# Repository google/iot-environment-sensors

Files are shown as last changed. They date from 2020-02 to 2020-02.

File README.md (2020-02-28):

This project demonstrates how an ESP32 can be combined with Google Cloud IoT, Google Cloud Functions, Google StackDriver and Google BigQuery to collect and analyze metrics from environmental sensors.

**This example is not an officially supported Google product, does not have a SLA/SLO, and should not be used in production.**

The project consists of three components:

- The Google Cloud Function - This is a simple Go-based piece of code. Simply configure the Cloud Function in the console to be triggered on a telemetry event from the IoT project.
- The firmware - This is an ESP-IDF project and must be built using the ESP-IDF toolset.
- A CAD model for the PCB design in [this repository](https://github.com/bobobo1618/iot-environment-sensor).

# Instructions

There are three things that have to be set up:

- The hardware
- The firmware
- The Google Cloud Platform project which will collect metrics for analysis

## Hardware

This has been tested with the PCB design from [this repository](https://github.com/bobobo1618/iot-environment-sensor). The board is intended to be combined with:

- A Sensirion SCD30 CO2 sensor, with a pin-header soldered to it.
- An Amphenol SM-UART-04L particulate sensor.
- An ESP32-PICO-KIT.

The board can be manufactured manually or by a PCB fab.

This repository also contains a FreeCAD model for a case intended to fit the PCB design.

## Google Cloud Platform

The project is intended to be used with:

- IoT Core: To act as a bridge between the MQTT protocol used by the sensors and Pubsub.
- Pubsub: To act as a bridge between IoT Core and Cloud Functions.
- StackDriver: For real-time monitoring and alerting on sensor readings.
- BigQuery: For long-term historical data collection and analysis.
- Cloud Functions: To ingest incoming data and store it in BigQuery and/or StackDriver.

The recommended setup procedure is (using the [Cloud SDK](https://cloud.google.com/sdk) CLI):

- Create a GCP project ([docs](https://cloud.google.com/resource-manager/docs/creating-managing-projects)): `gcloud projects create <PROJECT_ID>`
- Create an IoT Core registry in the region of your choice ([docs](https://cloud.google.com/iot/docs/how-tos/devices)): `gcloud iot registries create <REGISTRY_ID> --project=<PROJECT_ID> --region=<REGION>`
- Create the partitioned BigQuery table where your historical data will be stored ([docs](https://cloud.google.com/bigquery/docs/creating-column-partitions)): `bq mk --table --schema bqschema.json --time_partitioning_field Timestamp <PROJECT_ID>:<DATASET>.<TABLE>`
- Set up the Cloud Functions ([docs](https://cloud.google.com/functions/docs/deploying/filesystem)):
    - BigQuery: 
      ```bash
      gcloud functions deploy <NAME> \
        --runtime go111 \
        --trigger-topic telemetry \
        --entry-point GasTranslator \
        --memory 128MB \
        --source cloud_function \
        --set-env-vars=PROJECT_ID=<PROJECT_ID>,BQ_DATASET=<BQ_DATASET>,BQ_TABLE=<BQ_TABLE>
      ```
    - StackDriver:
    ```bash
      gcloud functions deploy <NAME> \
        --runtime go111 \
        --trigger-topic telemetry \
        --entry-point GasTranslatorStackdriver \
        --memory 128MB \
        --source cloud_function \
        --set-env-vars=PROJECT_ID=<PROJECT_ID>,SD_NAMESPACE=<SD_NAMESPACE>,SD_LOCATION=<SD_LOCATION>,
      ```

## Firmware

The firmware is an [Espressif ESP-IDF](https://docs.espressif.com/projects/esp-idf/en/latest/) project and in particular uses [arduino-esp32](https://github.com/espressif/arduino-esp32). As such, it depends on version 3.3.1 of ESP-IDF which can be installed following [these instructions](https://docs.espressif.com/projects/esp-idf/en/v3.3.1/get-started/index.html). arduino-esp32 frequently updates its IDF version so check the git log for the most recent commit hash:

```bash
cd firmware/components/arduino
git log --oneline --grep 'IDF' firmware/components/arduino/
```

Once you've set up ESP-IDF, you'll need to configure the project by running `idf.py menuconfig` from the firmware directory. In particular, under `Component Config -> Google IoT Configuration` there are options for the IoT Core project and registry, as well as the WiFi AP and password.

The firmware is also built with support for OTA firmware updates and requires that you generate an OTA signing key. To do so:

- Generate a private key: `espsecure.py generate_signing_key secure_boot_signing_key.pem`
- Generate a public key: `espsecure.py extract_public_key --keyfile secure_boot_signing_key.pem signature_verification_key.bin`

The next step is to build the firmware with `idf.py build`.

Finally, you need to flash the device and provision if for IoT Core. The `provision.sh` script does both.

### OTAs

The firmware assumes that the firmware update will be stored using Google Cloud Storage. If you want to store it elsewhere, you'll need to replace `googleca.pem` with the public certificate of the HTTPS server you intend to update from.

In order to send an OTA update, you must:

- Build: `idf.py build`
- Sign: `espsecure.py sign_data --keyfile secure_boot_signing_key.pem build/hello-world.bin`
- Upload to your HTTPS server: `gsutil cp -a public-read build/hello-world.bin gs://<your bucket>/firmware.bin`
- Send the update command using IoT Core:
  ```
  gcloud iot devices commands send \
    --device=<device id> \
    --project=<project> \
    --region=<region> \
    --registry=<registry> \
    --command-data='update: https://storage.googleapis.com/<your bucket>/firmware.bin'
  ```

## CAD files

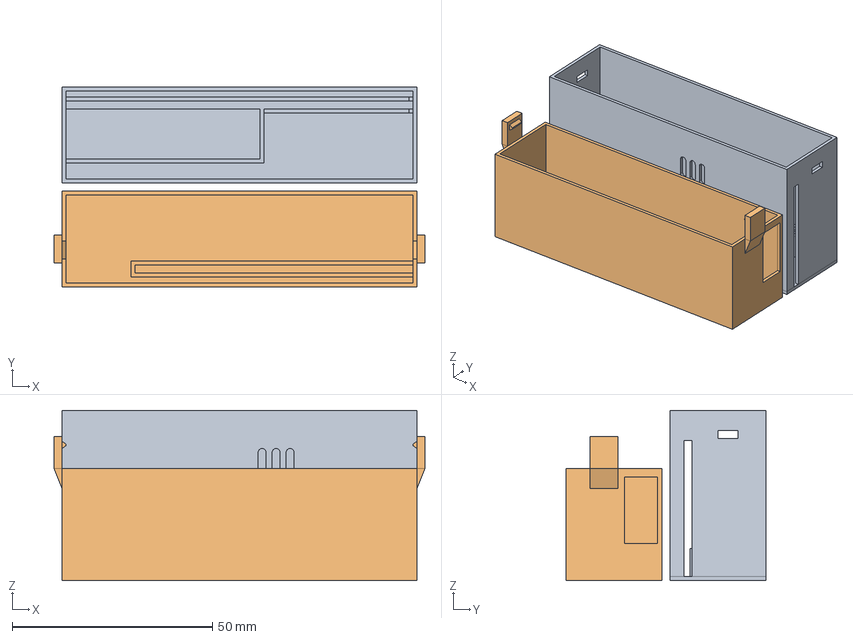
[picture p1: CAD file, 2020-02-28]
case_extended.FCStd
92.7 x 50.0 x 42.5 mm
CaseBody
LidBody

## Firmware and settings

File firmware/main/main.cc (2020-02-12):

// Copyright 2020 Google LLC
//
// Licensed under the Apache License, Version 2.0 (the "License");
// you may not use this file except in compliance with the License.
// You may obtain a copy of the License at
//
//      http://www.apache.org/licenses/LICENSE-2.0
//
// Unless required by applicable law or agreed to in writing, software
// distributed under the License is distributed on an "AS IS" BASIS,
// WITHOUT WARRANTIES OR CONDITIONS OF ANY KIND, either express or implied.
// See the License for the specific language governing permissions and
// limitations under the License.

#include <EEPROM.h>
#include <FS.h>
#include <HTTPClient.h>
#include <SPIFFS.h>
#include <WiFi.h>
#include <WiFiMulti.h>
#include <Wire.h>
#include <esp_system.h>
#include <freertos/FreeRTOS.h>
#include <freertos/task.h>

#include <array>
#include <cinttypes>
#include <string>

#include "google-mqtt.h"
#include "sensor_bmp280.h"
#include "sensor_scd30.h"
#include "sensor_sgp30.h"
#include "sensor_smuart04l.h"

SemaphoreHandle_t i2c_mutex;

#define WIFI_REPORTING_ENABLED
static const int num_sensors = 4;
HardwareSerial smuart04l_serial(1);

std::array<SensorWrapper *, num_sensors> sensors;
std::array<std::array<StackType_t, 8 * 1024>, num_sensors + 2> stacks;
std::array<StaticTask_t, num_sensors + 2> tasks;
std::vector<TemperatureSensor *> temperature_sensors;

void ServerUpdateLoopMqtt(void *pv_parameters) {
  std::vector<SensorWrapper *> sensor_vector;
  for (SensorWrapper *sensor : sensors) {
    sensor_vector.push_back(sensor);
  }
  SetupGoogleMQTT(sensor_vector, temperature_sensors);
  LoopGoogleMQTT();
}

void ServerWatchdogLoopMqtt(void *pv_parameters) { GoogleMQTTWatchdog(); }

void ScanI2c() {
  byte error, address;
  int num_devices;

  Serial.println("Scanning...");

  num_devices = 0;
  for (address = 1; address < 127; address++) {
    // The i2c_scanner uses the return value of
    // the Write.endTransmisstion to see if
    // a device did acknowledge to the address.
    Wire.beginTransmission(address);
    error = Wire.endTransmission();

    if (error == 0) {
      Serial.print("I2C device found at address 0x");
      if (address < 16) Serial.print("0");
      Serial.print(address, HEX);
      Serial.println("  !");

      num_devices++;
    } else if (error == 4) {
      Serial.print("Unknown error at address 0x");
      if (address < 16) Serial.print("0");
      Serial.println(address, HEX);
    }
  }
  if (num_devices == 0)
    Serial.println("No I2C devices found\n");
  else
    Serial.println("done\n");
}

void loop() {
  while (1) {
    vTaskDelay(portMAX_DELAY);
  }
}

void SensorWrapperLoop(void *pv_parameters) {
  SensorWrapper *wrapper = reinterpret_cast<SensorWrapper *>(pv_parameters);
  wrapper->Loop();
}

void setup() {
  i2c_mutex = xSemaphoreCreateMutex();

  /* Init I2C and serial communication */
  Serial.begin(115200);

  uint8_t mac[6];
  if (esp_efuse_mac_get_default(mac) != ESP_OK) {
    Serial.println("Failed to get MAC");
  } else {
    Serial.printf("MAC: ");
    for (int i = 0; i < 6; i++) {
      Serial.printf("%x", mac[i]);
    }
    Serial.printf("\n");
  }

  if (!SPIFFS.begin(true)) {
    Serial.println("SPIFFS failed");
    esp_restart();
  }

  {
    File file = SPIFFS.open("/mac.dat");
    if (!file || file.isDirectory()) {
      Serial.println("MAC file not present.");
      esp_restart();
    }

    uint8_t read_mac[6];
    if (file.readBytes((char *)(read_mac), 6) < 6) {
      Serial.println("MAC file too small.");
      esp_restart();
    }

    for (int i = 0; i < 6; i++) {
      if (read_mac[i] != mac[i]) {
        Serial.println("MAC mismatch.");
        esp_restart();
      }
    }
  }

  EEPROM.begin(4096);

  Wire.begin();
  ScanI2c();

  Bmp280Sensor *bmp280 = new Bmp280Sensor(&Serial, &i2c_mutex);
  Scd30Sensor *scd30 = new Scd30Sensor(&Serial, &i2c_mutex, bmp280);
  sensors = {
      bmp280,
      scd30,
      new Sgp30Sensor(&Serial, &i2c_mutex, scd30, scd30),
      new Smuart04lSensor(&Serial, &smuart04l_serial),
  };
  temperature_sensors = {scd30, bmp280};

  for (SensorWrapper *sensor : sensors) {
    sensor->Init();
  }

  for (int i = 0; i < sensors.size(); i++) {
    SensorWrapper *sensor = sensors[i];
    xTaskCreateStaticPinnedToCore(SensorWrapperLoop, "SensorLoop",
                                  stacks[i].size(), sensor, /*priority=*/1,
                                  stacks[i].data(), &tasks[i], 1);
  }

#ifdef WIFI_REPORTING_ENABLED
  xTaskCreateStaticPinnedToCore(ServerUpdateLoopMqtt, "ServerUpdateLoopMqtt",
                                stacks[sensors.size()].size(), nullptr,
                                /*priority=*/2, stacks[sensors.size()].data(),
                                &tasks[sensors.size()], 1);
  xTaskCreateStaticPinnedToCore(
      ServerWatchdogLoopMqtt, "ServerWatchdogLoopMqtt",
      stacks[sensors.size() + 1].size(), nullptr,
      /*priority=*/2, stacks[sensors.size() + 1].data(),
      &tasks[sensors.size() + 1], 1);
#endif
}

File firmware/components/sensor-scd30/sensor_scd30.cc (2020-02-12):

// Copyright 2020 Google LLC
//
// Licensed under the Apache License, Version 2.0 (the "License");
// you may not use this file except in compliance with the License.
// You may obtain a copy of the License at
//
//      http://www.apache.org/licenses/LICENSE-2.0
//
// Unless required by applicable law or agreed to in writing, software
// distributed under the License is distributed on an "AS IS" BASIS,
// WITHOUT WARRANTIES OR CONDITIONS OF ANY KIND, either express or implied.
// See the License for the specific language governing permissions and
// limitations under the License.

#include "sensor_scd30.h"

#include <array>
#include <string>

Scd30Sensor::Scd30Sensor(HardwareSerial* debug_serial,
                         SemaphoreHandle_t* i2c_mutex,
                         PressureSensor* pressure_sensor)
    : reading_{},
      failed_readings_(0),
      debug_serial_(*debug_serial),
      i2c_mutex_(*i2c_mutex),
      pressure_sensor_(pressure_sensor) {
  reading_mutex_ = xSemaphoreCreateMutex();
}

void Scd30Sensor::Init() {
  if (xSemaphoreTake(i2c_mutex_, 2000 / portTICK_PERIOD_MS) != pdPASS) {
    debug_serial_.println("SCD30: Couldn't acquire mutex for SCD30 init.");
    return;
  }
  if (!scd30_.begin()) {
    debug_serial_.println("SCD30: Failed to initialize SCD30.");
    xSemaphoreGive(i2c_mutex_);
    return;
  }
  if (!scd30_.setAutoSelfCalibration(true)) {
    debug_serial_.println("SCD30: Failed to enable SCD30 self calibration.");
    xSemaphoreGive(i2c_mutex_);
    return;
  }
  xSemaphoreGive(i2c_mutex_);
  debug_serial_.println("SCD30: SCD30 init complete.");
}

void Scd30Sensor::Loop() {
  vTaskDelay(10000 /
             portTICK_PERIOD_MS);  // Give it 10s for the BME680 to stabilize.
  int remaining_pressure_iterations = 0;
  uint16_t last_pressure = 0;
  while (1) {
    // Serial.println("Starting SCD30 iteration.");
    assert(heap_caps_check_integrity_all(true));
    if (xSemaphoreTake(i2c_mutex_, 2000 / portTICK_PERIOD_MS) != pdPASS) {
      debug_serial_.println("SCD30: Couldn't acquire mutex for SCD30 update.");
      continue;
    }
    if (scd30_.dataAvailable()) {
      if (!scd30_.readMeasurement()) {
        debug_serial_.println("SCD30: Failed to read SCD30 data.");
        failed_readings_++;
        xSemaphoreGive(i2c_mutex_);
        continue;
      }
      if (xSemaphoreTake(reading_mutex_, 2000 / portTICK_PERIOD_MS) != pdPASS) {
        debug_serial_.println(
            "SCD30: Couldn't acquire environment mutex for SCD30 update.");
        xSemaphoreGive(i2c_mutex_);
        continue;
      }
      reading_.co2 = scd30_.getCO2();
      reading_.temperature = scd30_.getTemperature();
      reading_.humidity = scd30_.getHumidity();
      debug_serial_.printf("SCD30: data %f, %f, %f\n", reading_.co2,
                           reading_.humidity, reading_.temperature);
      xSemaphoreGive(reading_mutex_);
    }
    if (remaining_pressure_iterations == 0) {
      if (pressure_sensor_ != nullptr) {
        const float raw_pressure = pressure_sensor_->GetPressure();
        if (raw_pressure < 800.0 || raw_pressure > 1200.0) {
          debug_serial_.printf("SCD30: Pressure too high to update: %f\n",
                               raw_pressure);
        } else {
          const uint16_t new_pressure =
              static_cast<uint16_t>(raw_pressure + 0.5f);
          if (new_pressure == last_pressure) {
            debug_serial_.println("SCD30: Skipping pressure update.");
          } else {
            debug_serial_.printf("SCD30: Setting pressure to %d\n",
                                 new_pressure);
            scd30_.setAmbientPressure(new_pressure);
            last_pressure = new_pressure;
          }
        }
      }
      remaining_pressure_iterations = 60;  // 10 minutes.
    } else {
      remaining_pressure_iterations--;
    }
    xSemaphoreGive(i2c_mutex_);
    assert(heap_caps_check_integrity_all(true));
    const uint32_t t_ms = 2000;
    const TickType_t t_ticks = t_ms / portTICK_PERIOD_MS;
    // debug_serial_.printf("SCD30 sleeping for %ums, %u ticks\n", t_ms,
    // t_ticks);
    vTaskDelay(t_ticks);
  }
}

void Scd30Sensor::CalibrateTemperature(float actual_temp) {
  debug_serial_.printf("SCD30: Calibrating temperature - %f\n", actual_temp);
  if (xSemaphoreTake(reading_mutex_, 2000 / portTICK_PERIOD_MS) != pdPASS) {
    debug_serial_.println(
        "SCD30: Couldn't acquire environment mutex for calibration.");
    return;
  }
  const float original_reading = reading_.temperature;
  xSemaphoreGive(reading_mutex_);
  const float delta = actual_temp - original_reading;
  debug_serial_.printf("SCD30: Temperature delta %f - %f = %f\n", actual_temp,
                       original_reading, delta);
  if (xSemaphoreTake(i2c_mutex_, 2000 / portTICK_PERIOD_MS) != pdPASS) {
    debug_serial_.println("SCD30: Couldn't acquire mutex for calibration.");
    return;
  }
  scd30_.sendCommand(COMMAND_SET_TEMPERATURE_OFFSET);
  uint8_t res[3];
  Wire.requestFrom(SCD30_ADDRESS, 3);
  const size_t bytes_read = Wire.readBytes(res, 3);
  if (bytes_read != 3) {
    debug_serial_.printf(
        "SCD30: Couldn't get temperature offset, read failed (%d != 3)\n",
        bytes_read);
    xSemaphoreGive(i2c_mutex_);
    return;
  }

  const uint8_t crc = scd30_.computeCRC8(res, 2);
  if (crc != res[2]) {
    debug_serial_.println("SCD30: temperature offset CRC failed.");
    xSemaphoreGive(i2c_mutex_);
    return;
  }

  const uint8_t original_offset_msb = res[0];
  const uint8_t original_offset_lsb = res[1];
  const uint16_t original_offset =
      ((uint16_t)original_offset_msb << 8 | original_offset_lsb);
  const int32_t new_offset = original_offset + (delta * -100.0f);
  const uint16_t final_new_offset =
      (new_offset < 0 || new_offset > 2000) ? 0 : new_offset;

  debug_serial_.printf(
      "SDC30: Original offset %d, new offset %d, final offset %d\n",
      original_offset, new_offset, final_new_offset);
  scd30_.sendCommand(COMMAND_SET_TEMPERATURE_OFFSET, final_new_offset);
  xSemaphoreGive(i2c_mutex_);
}

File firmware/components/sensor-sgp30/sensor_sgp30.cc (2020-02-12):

// Copyright 2020 Google LLC
//
// Licensed under the Apache License, Version 2.0 (the "License");
// you may not use this file except in compliance with the License.
// You may obtain a copy of the License at
//
//      http://www.apache.org/licenses/LICENSE-2.0
//
// Unless required by applicable law or agreed to in writing, software
// distributed under the License is distributed on an "AS IS" BASIS,
// WITHOUT WARRANTIES OR CONDITIONS OF ANY KIND, either express or implied.
// See the License for the specific language governing permissions and
// limitations under the License.

#include "sensor_sgp30.h"

#include <SPIFFS.h>

#include <array>
#include <cmath>

Sgp30Sensor::Sgp30Sensor(HardwareSerial* debug_serial,
                         SemaphoreHandle_t* i2c_mutex,
                         TemperatureSensor* temperature_sensor,
                         HumiditySensor* humidity_sensor)
    : reading_{},
      failed_readings_(0),
      debug_serial_(*debug_serial),
      i2c_mutex_(*i2c_mutex),
      reading_mutex_(xSemaphoreCreateMutex()),
      temperature_sensor_(temperature_sensor),
      humidity_sensor_(humidity_sensor),
      abs_humidity_hardware_format_(0),
      abs_humidity_(0) {}

const char* baseline_filename = "/sgp30_baselines.dat";

bool GetSgpFile(const char* path, size_t expected_size, char* contents) {
  File file = SPIFFS.open(path);
  if (!file || file.isDirectory()) {
    Serial.printf("SPIFFS: File not present: %s\n", path);
    return false;
  }

  if (file.readBytes(contents, expected_size) < expected_size) {
    Serial.printf("SPIFFS: File %s not correct length.\n", path);
    return false;
  }
  return true;
}

void Sgp30Sensor::Init() {
  uint16_t baselines[2];
  const bool baselines_read =
      GetSgpFile(baseline_filename, 4, (char*)baselines);

  if (xSemaphoreTake(i2c_mutex_, 2000 / portTICK_PERIOD_MS) != pdPASS) {
    debug_serial_.println("SGP30: Couldn't acquire mutex for SGP30 init.");
    return;
  }
  if (!sgp30_.begin()) {
    debug_serial_.println("SGP30: Failed to init SGP30.");
  }
  sgp30_.initAirQuality();
  if (baselines_read) {
    debug_serial_.println("SGP30: Setting baselines.");
    sgp30_.setBaseline(baselines[0], baselines[1]);
  }
  xSemaphoreGive(i2c_mutex_);
  debug_serial_.println("SGP30: SGP30 init complete.");
}

uint16_t Sgp30Sensor::AbsHumidityForSensor(float relative_humidity,
                                           float temperature) {
  // From
  // https://carnotcycle.wordpress.com/2012/08/04/how-to-convert-relative-humidity-to-absolute-humidity/
  abs_humidity_ = ((6.112 * exp((17.67 * temperature) / (temperature + 243.5)) *
                    relative_humidity * 2.1674) /
                   (273.15 + temperature));
  debug_serial_.printf(
      "SGP30: Temp: %.2f°C, Hum: %.2f%%, Abs. Hum: %.2fg/m^3\n", temperature,
      relative_humidity, abs_humidity_);
  const uint32_t abs_humidity = abs_humidity_ * 1000.0f;
  const uint16_t ah_scaled = (uint16_t)((abs_humidity * 16777) >> 16);
  return ah_scaled;
}

void Sgp30Sensor::Loop() {
  int iterations_until_humidity_update = 20;
  int iterations_until_baseline_update = 30;
  while (1) {
    vTaskDelay(1000 / portTICK_PERIOD_MS);

    if (iterations_until_humidity_update == 0 &&
        temperature_sensor_ != nullptr && humidity_sensor_ != nullptr) {
      float relative_humidity = humidity_sensor_->GetHumidity();
      float temperature = temperature_sensor_->GetTemperature();
      if (relative_humidity != 0 && temperature != 0) {
        abs_humidity_hardware_format_ =
            AbsHumidityForSensor(relative_humidity, temperature);
      }
      iterations_until_humidity_update = 60;
    } else {
      iterations_until_humidity_update--;
    }

    if (xSemaphoreTake(i2c_mutex_, 2000 / portTICK_PERIOD_MS) != pdPASS) {
      debug_serial_.println("SGP30: Couldn't acquire mutex for SGP30 update.");
      continue;
    }

    if (abs_humidity_hardware_format_ != 0) {
      sgp30_.setHumidity(abs_humidity_hardware_format_);
    }

    SGP30ERR result = sgp30_.measureAirQuality();

    if (result != SGP30ERR::SUCCESS) {
      debug_serial_.printf("SGP30: SGP30 status was not success, was %u\n",
                           result);
      failed_readings_++;
      xSemaphoreGive(i2c_mutex_);
      continue;
    }

    result = sgp30_.getBaseline();
    if (result != SGP30ERR::SUCCESS) {
      debug_serial_.printf(
          "SGP30: SGP30 baseline status was not success, was %u\n", result);
      failed_readings_++;
    }

    result = sgp30_.measureRawSignals();
    if (result != SGP30ERR::SUCCESS) {
      debug_serial_.printf(
          "SGP30: SGP30 raw signal status was not success, was %u\n", result);
      failed_readings_++;
    }
    xSemaphoreGive(i2c_mutex_);

    if (xSemaphoreTake(reading_mutex_, 2000 / portTICK_PERIOD_MS) != pdPASS) {
      debug_serial_.println(
          "SGP30: Couldn't acquire environment mutex for SGP30 update.");
    }
    reading_.co2 = sgp30_.CO2;
    reading_.tvoc = sgp30_.TVOC;
    reading_.baseline_co2 = sgp30_.baselineCO2;
    reading_.baseline_tvoc = sgp30_.baselineTVOC;
    reading_.h2 = sgp30_.H2;
    reading_.ethanol = sgp30_.ethanol;
    xSemaphoreGive(reading_mutex_);

    debug_serial_.printf("SGP30: Got readings from SGP30: ");
    for (int i = 0; i < 6; i++) {
      debug_serial_.printf("%u ", *(&reading_.co2 + i));
    }
    debug_serial_.printf("\n");

    if (iterations_until_baseline_update == 0) {
      debug_serial_.println("SGP30: Saving baselines.");

      File file = SPIFFS.open(baseline_filename, "w");
      if (!file || file.isDirectory()) {
        debug_serial_.printf("SGP30: File not present: %s\n",
                             baseline_filename);
      } else {
        const uint16_t baselines[] = {sgp30_.baselineCO2, sgp30_.baselineTVOC};
        if (file.write((uint8_t*)baselines, 4) != 4) {
          debug_serial_.println("SGP30: Failed to write baselines.");
        }
      }
      iterations_until_baseline_update = 3600 * 24;
    } else {
      iterations_until_baseline_update--;
    }
  }
}

void Sgp30Sensor::UpdateSensor(SensorUpdate* update) {
  xSemaphoreTake(reading_mutex_, portMAX_DELAY);
  update->sgp30->co2 = reading_.co2;
  update->sgp30->has_co2 = true;
  update->sgp30->tvoc = reading_.tvoc;
  update->sgp30->has_tvoc = true;
  update->sgp30->baseline_co2 = reading_.baseline_co2;
  update->sgp30->has_baseline_co2 = true;
  update->sgp30->baseline_tvoc = reading_.baseline_tvoc;
  update->sgp30->has_baseline_tvoc = true;
  update->sgp30->h2 = reading_.h2;
  update->sgp30->has_h2 = true;
  update->sgp30->ethanol = reading_.ethanol;
  update->sgp30->has_ethanol = true;
  xSemaphoreGive(reading_mutex_);
};

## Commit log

2020-02-10 Add first code
    [partition-table.csv]
2020-02-11 Use correct define name
    [google-mqtt.cc]
2020-02-11 Don't use a symlink for Arduino component
2020-02-28 Add case CAD model
    [case_extended.FCStd]
2020-07-03 Add column to BigQuery for physical device location
